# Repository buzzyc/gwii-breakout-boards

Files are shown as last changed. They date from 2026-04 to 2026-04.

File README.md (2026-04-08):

# G-Wii Breakout Boards

Custom KiCad breakout PCBs designed for the **G-Wii portable Wii** project. These boards replace the dozens of individual signal wires typically needed between the two halves of a portable Wii build with clean, modular PCBs and FFC (flat flex cable) connections.

Built in **KiCad 9.0**.

## Boards

### Daughterboard (`Daughterboard/`)
The central connector hub. Interfaces with the trimmed Wii motherboard and consolidates all control, audio, and video signals into organized connectors. Features a **GC+2.0** controller interface IC and a **UAMP** audio amplifier, routing button inputs (A/B/X/Y/Z, D-pad, triggers), analog stick axes, and stereo audio through a single interconnect system.

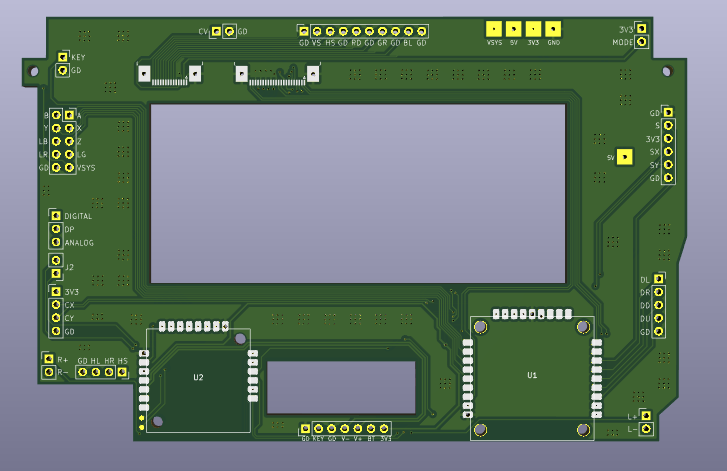
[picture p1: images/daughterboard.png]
Daughterboard PCB render


### Video FLX (`Video_FLX/`)
Video and signal breakout board that routes RGB video (RED, GREEN, BLUE), sync signals (H-Sync, V-Sync), audio lines, and control signals between the two halves of the portable via FFC cables — replacing what would otherwise be 20–30 individual wires.

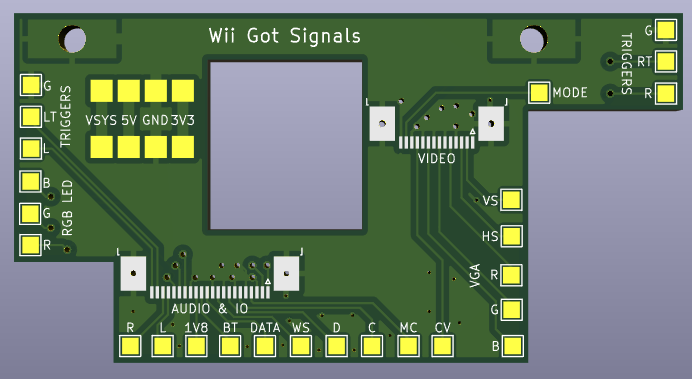
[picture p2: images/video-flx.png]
Video FLX PCB render


### ABXY (`ABXY/`)
Face button PCB for the A, B, X, Y, and Z buttons. Uses ALPS SKEYACA010 tactile switches and routes all button signals through a 6-pin connector back to the daughterboard. Also includes a mount for a common-anode tricolour (RGB) LED.

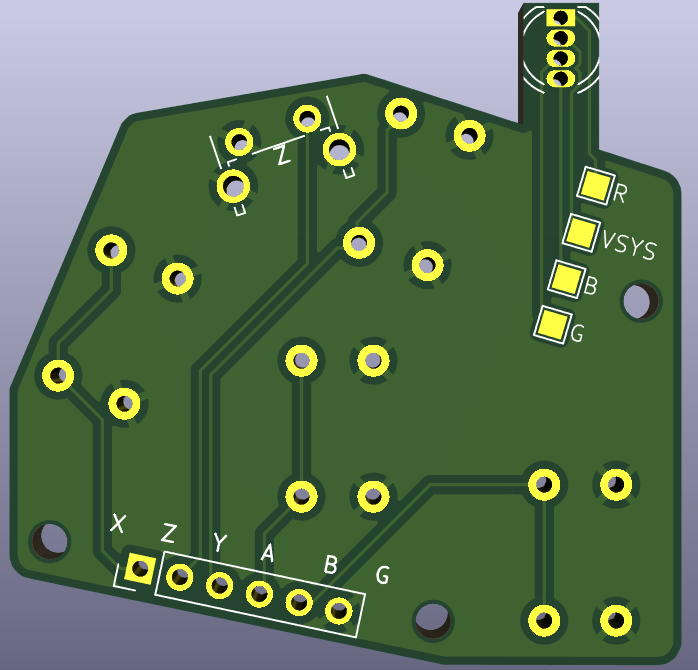
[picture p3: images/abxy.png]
ABXY PCB render


### D-Pad (`DPAD/`)
Directional pad button PCB for Up, Down, Left, and Right inputs.

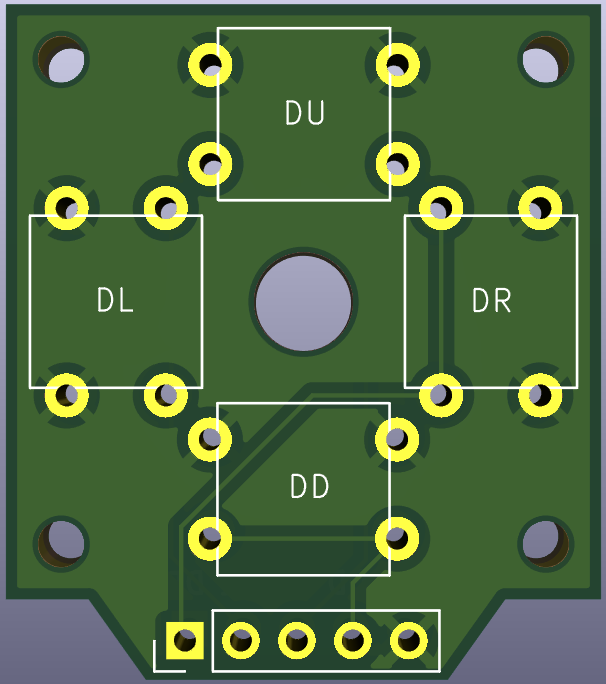
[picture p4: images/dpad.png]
D-Pad PCB render


### Joystick (`joystick/`)
Analog joystick breakout board. Provides connectors for joystick axis signals and mounting, routing back to the daughterboard.

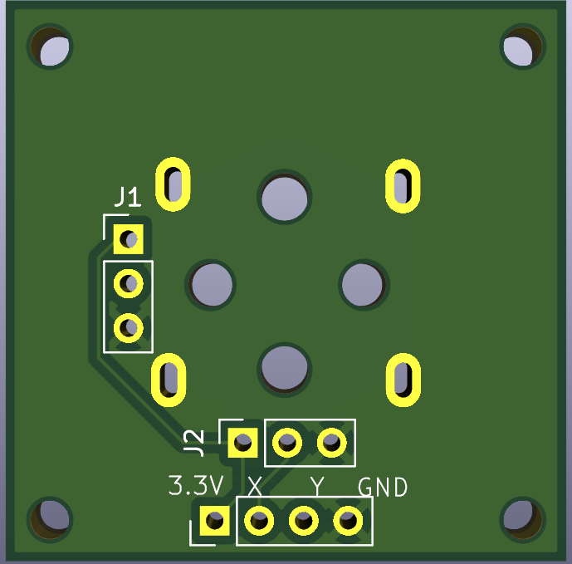
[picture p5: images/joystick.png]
Joystick PCB render


### Tactile Mount (`tactmount/`)
Tactile switch mounting board for auxiliary controls (Start, Select, Home, volume, etc.). Includes signal conditioning with pull-up resistors and decoupling capacitors.

The footprint labelled **SYNC** can act as either **SOURCE** or **Bluetooth sync** button depending on jumper configuration — position both jumpers at **1&2** for video source, or **2&3** for BT sync.

The resistor ladder on this board is designed around the **ZJ050NA-08C-KYV-N2** black VGA driver board (board reference](https://bitbuilt.net/forums/threads/resistor-value.6798/)).

Tactile Mount PCB front
Tactile Mount PCB rear

## Shared Libraries

- **`4LAYER_FOOTPRINTS.pretty`** — Custom footprints for 4LayerTech components (GC+2.0, PMS, UAMP, etc.)
- **`4LAYER_SCHEMATIC_SYMBOLS`** — Matching schematic symbols
- **`ALPS.pretty`** — ALPS SKEYACA010 tactile switch footprint (custom library — **note:** one of the GND pads is on the wrong side in the current footprint)

## Project Context

The [G-Wii](https://bitbuilt.net/forums/) is a portable Wii console build from the [BitBuilt](https://bitbuilt.net/) community. It uses a trimmed Wii motherboard fitted into a custom handheld case. These breakout boards make wiring significantly cleaner and more reliable by consolidating signals onto PCBs connected via FFC cables.

## License

Open hardware — use and modify freely for your own portable Wii builds.

> **Note:** These boards are not perfect and are provided as-is. You are more than welcome to modify them to suit your build.

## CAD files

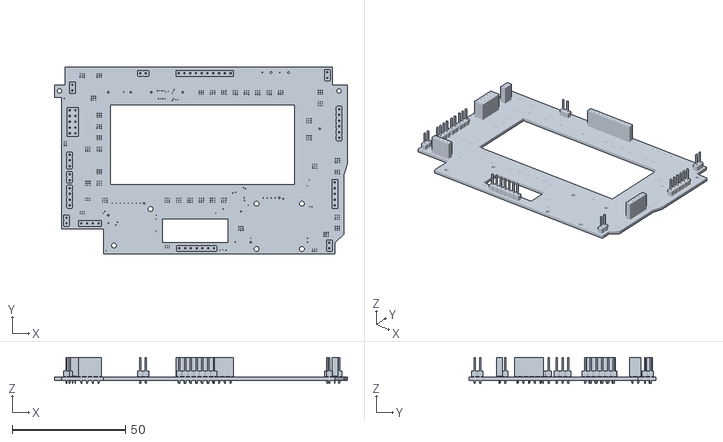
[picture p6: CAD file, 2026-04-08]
Daughterboard/daughterboard.stl
129.2 x 82.4 x 11.6

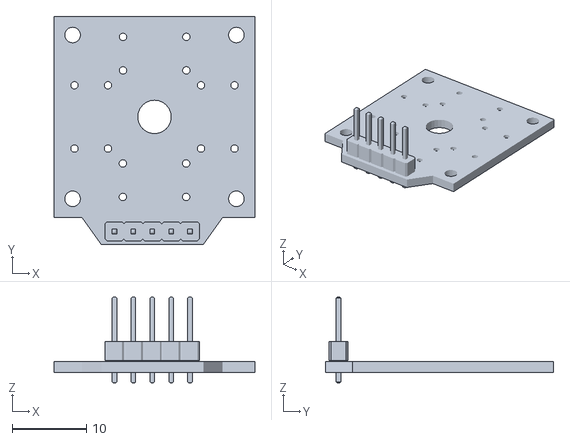
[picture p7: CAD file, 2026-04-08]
DPAD/DPAD.stl
27.0 x 30.7 x 11.5

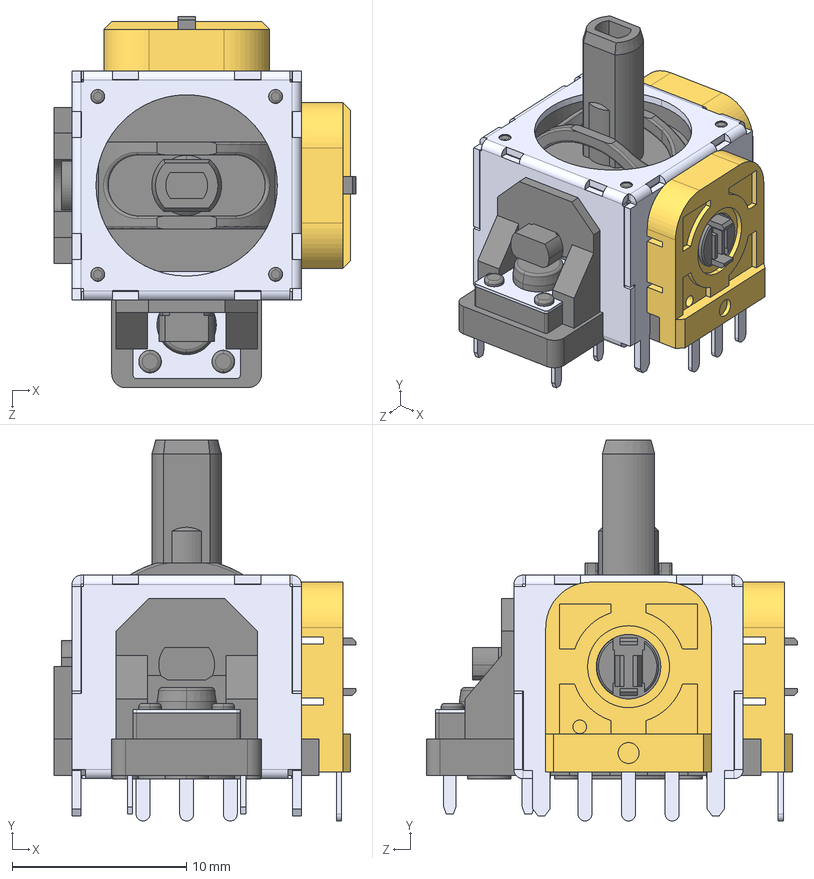
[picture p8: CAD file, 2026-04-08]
joystick/THB001P/THB001P.step
17.3 x 21.9 x 21.3 mm

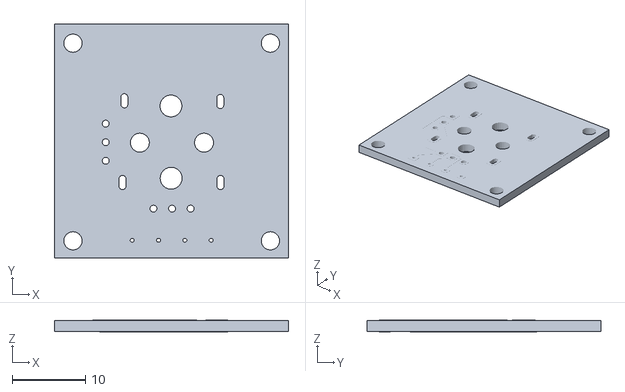
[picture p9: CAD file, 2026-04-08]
joystick/wii_breakout.stl
32.0 x 32.0 x 1.59

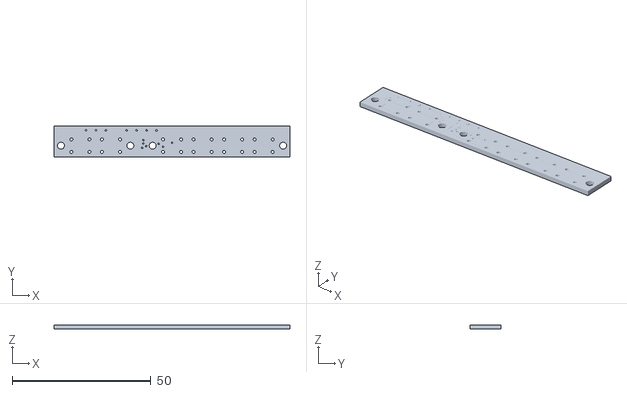
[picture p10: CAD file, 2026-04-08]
tactmount/tactmount.stl
85.0 x 11.0 x 1.58

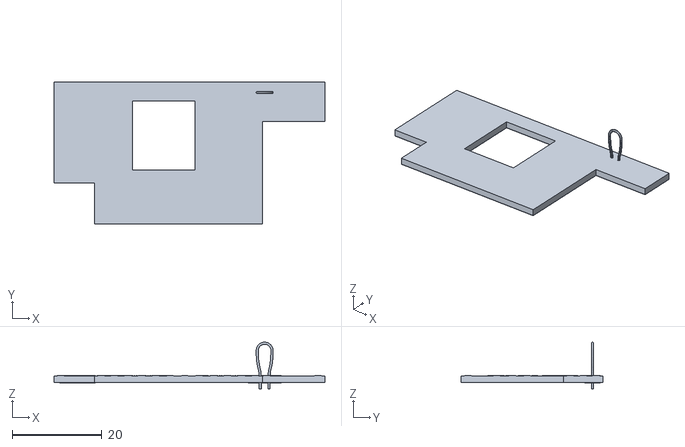
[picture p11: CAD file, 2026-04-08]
Video_FLX/video_flx.stl
60.5 x 31.6 x 10.4

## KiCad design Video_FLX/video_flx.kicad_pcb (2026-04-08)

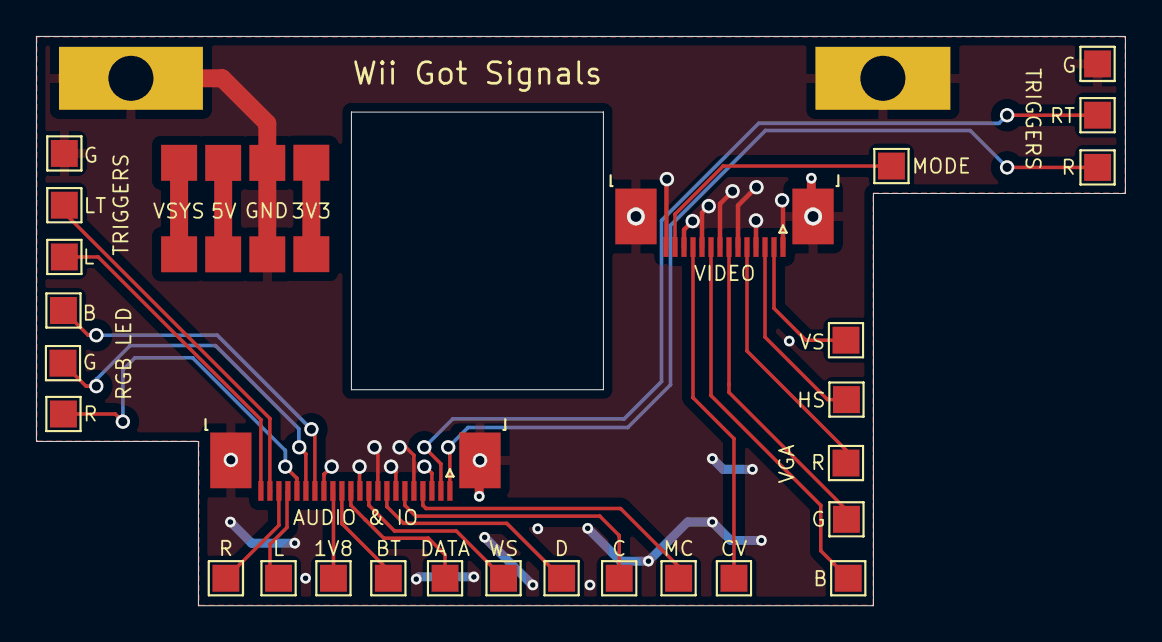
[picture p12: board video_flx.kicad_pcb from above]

Board: 2 copper layers, 60.5 x 31.6 mm, 27 parts (0 on the bottom side), 24 nets.

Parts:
1V8: TEST_1P; TestPoint_Pad_1.5x1.5mm
AUDIO & IO: Conn_01x16_MountingPin; TE_2-1734839-2_1x22-1MP_P0.5mm_Horizontal
B: TEST_1P; TestPoint_Pad_1.5x1.5mm
B#2: TEST_1P; TestPoint_Pad_1.5x1.5mm
BT: TEST_1P; TestPoint_Pad_1.5x1.5mm
C: TEST_1P; TestPoint_Pad_1.5x1.5mm
CV: TEST_1P; TestPoint_Pad_1.5x1.5mm
D: TEST_1P; TestPoint_Pad_1.5x1.5mm
DATA: TEST_1P; TestPoint_Pad_1.5x1.5mm
G: TEST_1P; TestPoint_Pad_1.5x1.5mm
G#2, G#3, G#4: TEST_1P; TestPoint_Pad_1.5x1.5mm
HS: TEST_1P; TestPoint_Pad_1.5x1.5mm
L: TEST_1P; TestPoint_Pad_1.5x1.5mm
L#2: TEST_1P; TestPoint_Pad_1.5x1.5mm
LT: TEST_1P; TestPoint_Pad_1.5x1.5mm
MC: TEST_1P; TestPoint_Pad_1.5x1.5mm
MODE: TEST_1P; TestPoint_Pad_1.5x1.5mm
R: TEST_1P; TestPoint_Pad_1.5x1.5mm
R#2, R#3, R#4: TEST_1P; TestPoint_Pad_1.5x1.5mm
RT: TEST_1P; TestPoint_Pad_1.5x1.5mm
VIDEO: Conn_01x14_MountingPin; TE_1-1734839-4_1x14-1MP_P0.5mm_Horizontal
VS: TEST_1P; TestPoint_Pad_1.5x1.5mm
WS: TEST_1P; TestPoint_Pad_1.5x1.5mm

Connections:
+1V8: 1V8.1, AUDIO & IO.14
BLUE: B.1, VIDEO.9
BT: AUDIO & IO.13, BT.1
C: AUDIO & IO.6, C.1
CDATA: AUDIO & IO.12, DATA.1
CV: CV.1, VIDEO.11
D: AUDIO & IO.8, D.1
GND: AUDIO & IO.3, AUDIO & IO.5, AUDIO & IO.7, AUDIO & IO.9, AUDIO & IO.11, AUDIO & IO.15, AUDIO & IO.MP (MountPin), G#2.1, G#4.1, VIDEO.1, VIDEO.4, VIDEO.6, VIDEO.8, VIDEO.10, VIDEO.12, VIDEO.14, VIDEO.MP (MountPin)
GREEN: G#3.1, VIDEO.7
HS: HS.1, VIDEO.3
L: AUDIO & IO.19, L.1
LA: AUDIO & IO.22, L#2.1
LEDB: AUDIO & IO.16, B#2.1
LEDG: AUDIO & IO.17, G.1
LEDR: AUDIO & IO.18, R#2.1
LT: AUDIO & IO.21, LT.1
MC: AUDIO & IO.4, MC.1
MODE: MODE.1, VIDEO.13
R: AUDIO & IO.20, R#3.1
RA: AUDIO & IO.1, R.1
RED: R#4.1, VIDEO.5
RT: AUDIO & IO.2, RT.1
VS: VIDEO.2, VS.1
WS: AUDIO & IO.10, WS.1

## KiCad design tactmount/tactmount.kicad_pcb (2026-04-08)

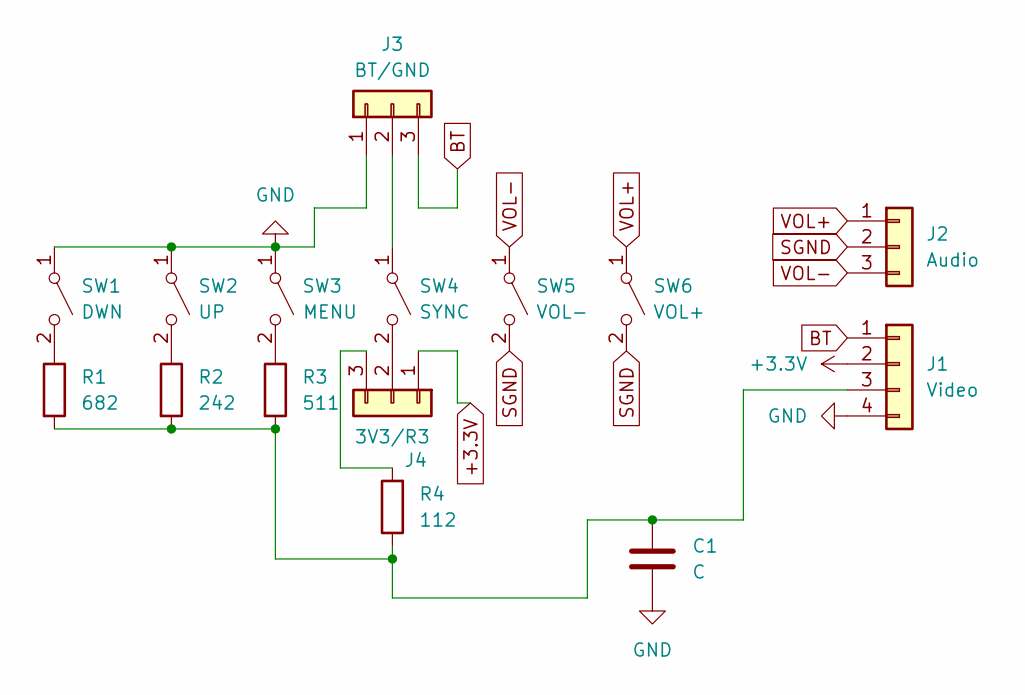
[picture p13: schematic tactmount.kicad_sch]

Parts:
C1: C; C_0603_1608Metric_Pad1.08x0.95mm_HandSolder
J1: Video; SolderWire-0.1sqmm_1x04_P3.6mm_D0.4mm_OD1mm
J2: Audio; SolderWire-0.1sqmm_1x03_P3.6mm_D0.4mm_OD1mm
J3: BT/GND; PinHeader_1x03_P2.54mm_Vertical
J4: 3V3/R3; PinHeader_1x03_P2.54mm_Vertical
R1: 682; R_0603_1608Metric_Pad0.98x0.95mm_HandSolder
R2: 242; R_0603_1608Metric_Pad0.98x0.95mm_HandSolder
R3: 511; R_0603_1608Metric_Pad0.98x0.95mm_HandSolder
R4: 112; R_0603_1608Metric_Pad0.98x0.95mm_HandSolder
SW1: DWN; SW_PUSH_6mm_H7.3mm
SW2: UP; SW_PUSH_6mm_H7.3mm
SW3: MENU; SW_PUSH_6mm_H7.3mm
SW4: SYNC; SW_PUSH_6mm_H7.3mm
SW5: VOL-; SW_PUSH_6mm_H7.3mm
SW6: VOL+; SW_PUSH_6mm_H7.3mm

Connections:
+3.3V: J1.2, J4.1
BT: J1.1, J3.3
GND: C1.2, J1.4, J3.1, SW1.1 (A), SW2.1 (A), SW3.1 (A)
unnamed: C1.1, J1.3, R1.2, R2.2, R3.2, R4.1
unnamed: J3.2, SW4.1 (A)
unnamed: J4.2, SW4.2 (B)
unnamed: J4.3, R4.2
unnamed: R1.1, SW1.2 (B)
unnamed: R2.1, SW2.2 (B)
unnamed: R3.1, SW3.2 (B)
SGND: J2.2, SW5.2 (B), SW6.2 (B)
VOL+: J2.1, SW6.1 (A)
VOL-: J2.3, SW5.1 (A)

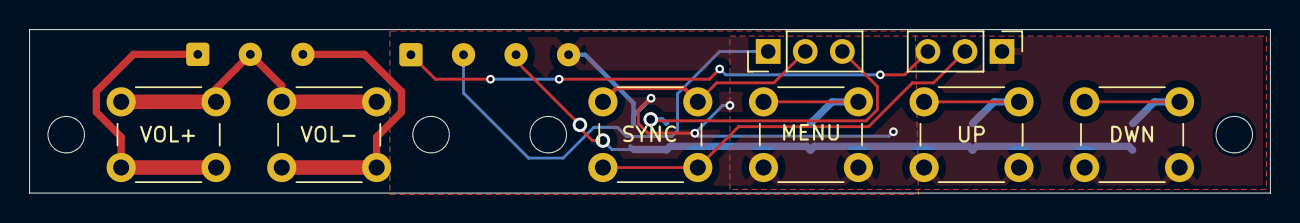
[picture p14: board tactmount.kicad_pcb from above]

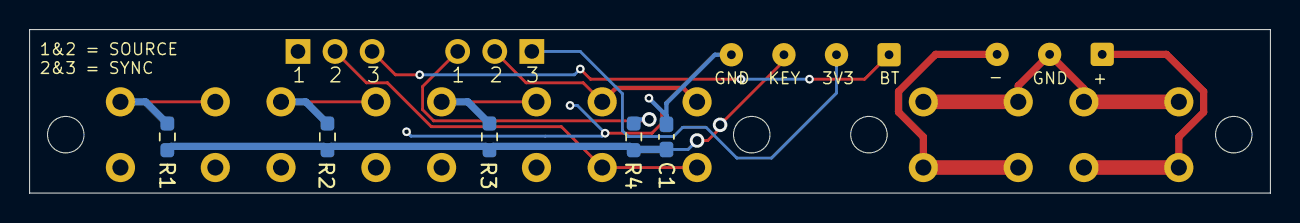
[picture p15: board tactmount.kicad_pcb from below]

Board: 2 copper layers, 85.0 x 11.2 mm, 15 parts (5 on the bottom side), 13 nets.

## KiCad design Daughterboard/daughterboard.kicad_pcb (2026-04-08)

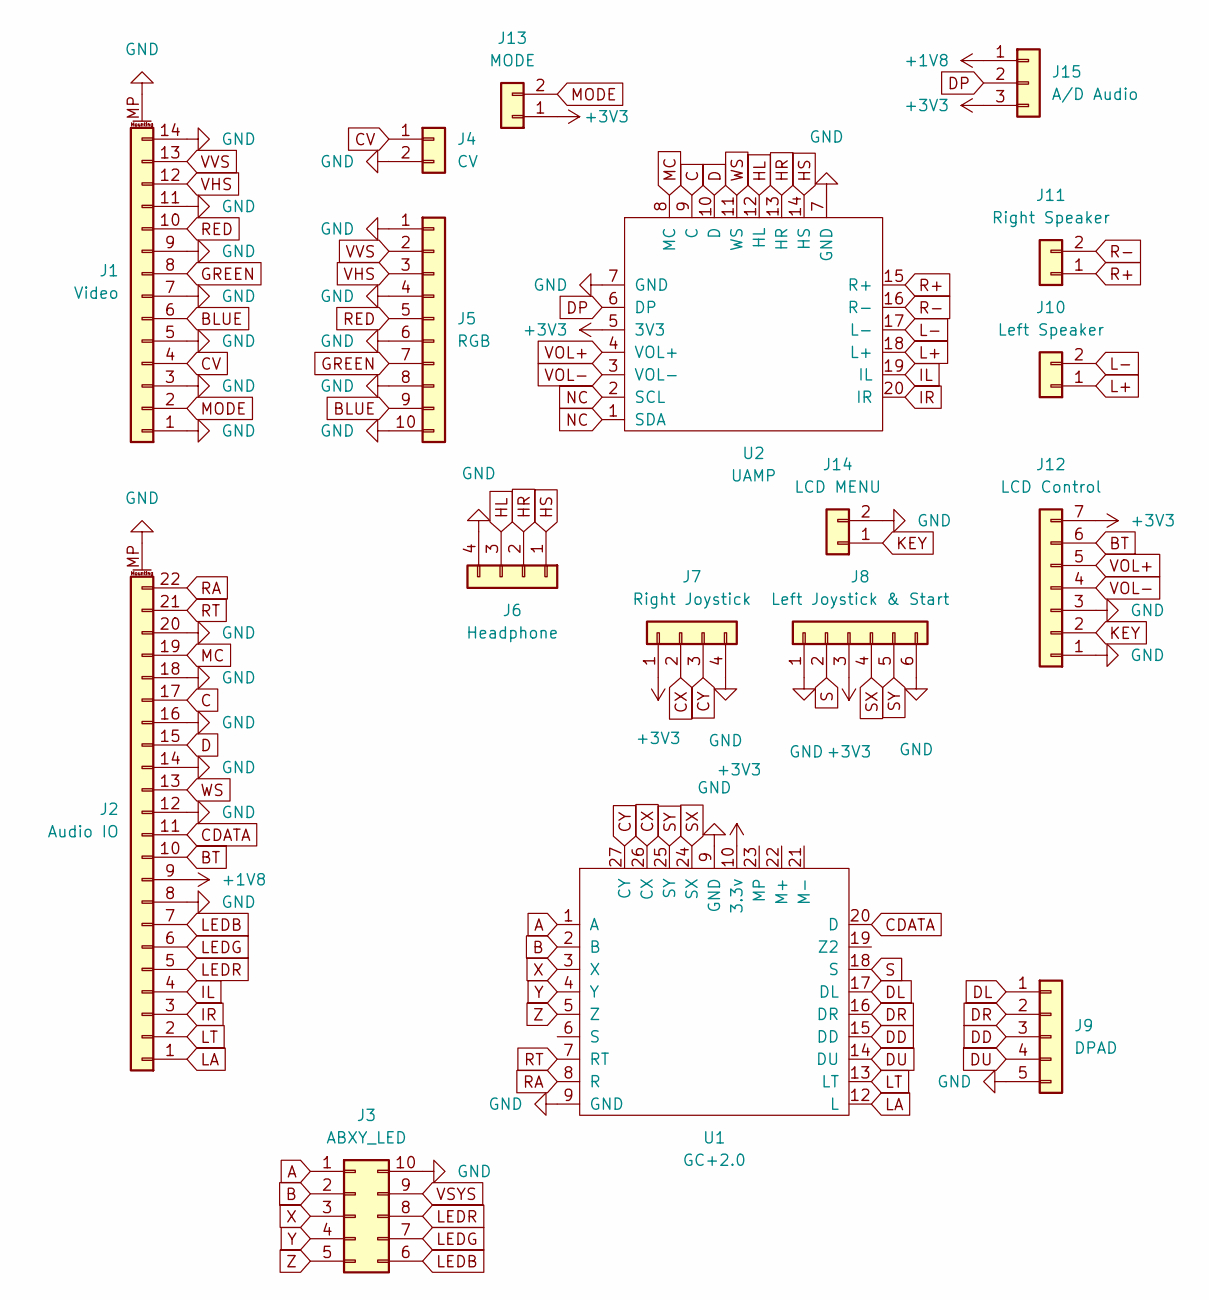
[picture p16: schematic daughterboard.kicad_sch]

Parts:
J1: Video; TE_1-1734839-4_1x14-1MP_P0.5mm_Horizontal
J2: Audio IO; TE_2-1734839-2_1x22-1MP_P0.5mm_Horizontal
J3: ABXY_LED; PinSocket_2x05_P2.54mm_Vertical
J4: CV; PinHeader_1x02_P2.54mm_Vertical
J5: RGB; PinSocket_1x10_P2.54mm_Vertical
J6: Headphone; PinSocket_1x04_P2.54mm_Vertical
J7: Right Joystick; PinHeader_1x04_P2.54mm_Vertical
J8: Left Joystick & Start; PinHeader_1x06_P2.54mm_Vertical
J9: DPAD; PinSocket_1x05_P2.54mm_Vertical
J10: Left Speaker; PinHeader_1x02_P2.54mm_Vertical
J11: Right Speaker; PinHeader_1x02_P2.54mm_Vertical
J12: LCD Control; PinHeader_1x07_P2.54mm_Vertical
J13: MODE; PinHeader_1x02_P2.54mm_Vertical
J14: LCD MENU; PinSocket_1x02_P2.54mm_Vertical
J15: A/D Audio; PinHeader_1x03_P2.54mm_Vertical
U1: GC+2.0
U2: UAMP; UAMP2

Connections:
+1V8: J2.9, J15.1
+3V3: J7.1, J8.3, J12.7, J13.1, J15.3, U1.10 (3.3v), U2.5 (3V3)
A: J3.1, U1.1 (A)
B: J3.2, U1.2 (B)
BLUE: J1.6, J5.9
BT: J2.10, J12.6
C: J2.17, U2.9 (C)
CDATA: J2.11, U1.20 (D)
CV: J1.4, J4.1
CX: J7.2, U1.26 (CX)
CY: J7.3, U1.27 (CY)
D: J2.15, U2.10 (D)
DD: J9.3, U1.15 (DD)
DL: J9.1, U1.17 (DL)
DP: J15.2, U2.6 (DP)
DR: J9.2, U1.16 (DR)
DU: J9.4, U1.14 (DU)
GND: J1.1, J1.3, J1.5, J1.7, J1.9, J1.11, J1.14, J1.MP (MountPin), J2.8, J2.12, J2.14, J2.16, J2.18, J2.20, J2.MP (MountPin), J3.10, J4.2, J5.1, J5.4, J5.6, J5.8, J5.10, J6.4, J7.4, J8.1, J8.6, J9.5, J12.1, J12.3, J14.2, U1.9 (GND), U2.7 (GND)
GREEN: J1.8, J5.7
HL: J6.3, U2.12 (HL)
HR: J6.2, U2.13 (HR)
HS: J6.1, U2.14 (HS)
IL: J2.4, U2.19 (IL)
IR: J2.3, U2.20 (IR)
KEY: J12.2, J14.1
L+: J10.1, U2.18 (L+)
L-: J10.2, U2.17 (L-)
LA: J2.1, U1.12 (L)
LEDB: J2.7, J3.6
LEDG: J2.6, J3.7
LEDR: J2.5, J3.8
LT: J2.2, U1.13 (LT)
MC: J2.19, U2.8 (MC)
MODE: J1.2, J13.2
R+: J11.1, U2.15 (R+)
R-: J11.2, U2.16 (R-)
RA: J2.22, U1.8 (R)
RED: J1.10, J5.5
RT: J2.21, U1.7 (RT)
S: J8.2, U1.18 (S)
SX: J8.4, U1.24 (SX)
SY: J8.5, U1.25 (SY)
VHS: J1.12, J5.3
VOL+: J12.5, U2.4 (VOL+)
VOL-: J12.4, U2.3 (VOL-)
VSYS: J3.9
VVS: J1.13, J5.2
WS: J2.13, U2.11 (WS)
X: J3.3, U1.3 (X)
Y: J3.4, U1.4 (Y)
Z: J3.5, U1.5 (Z)

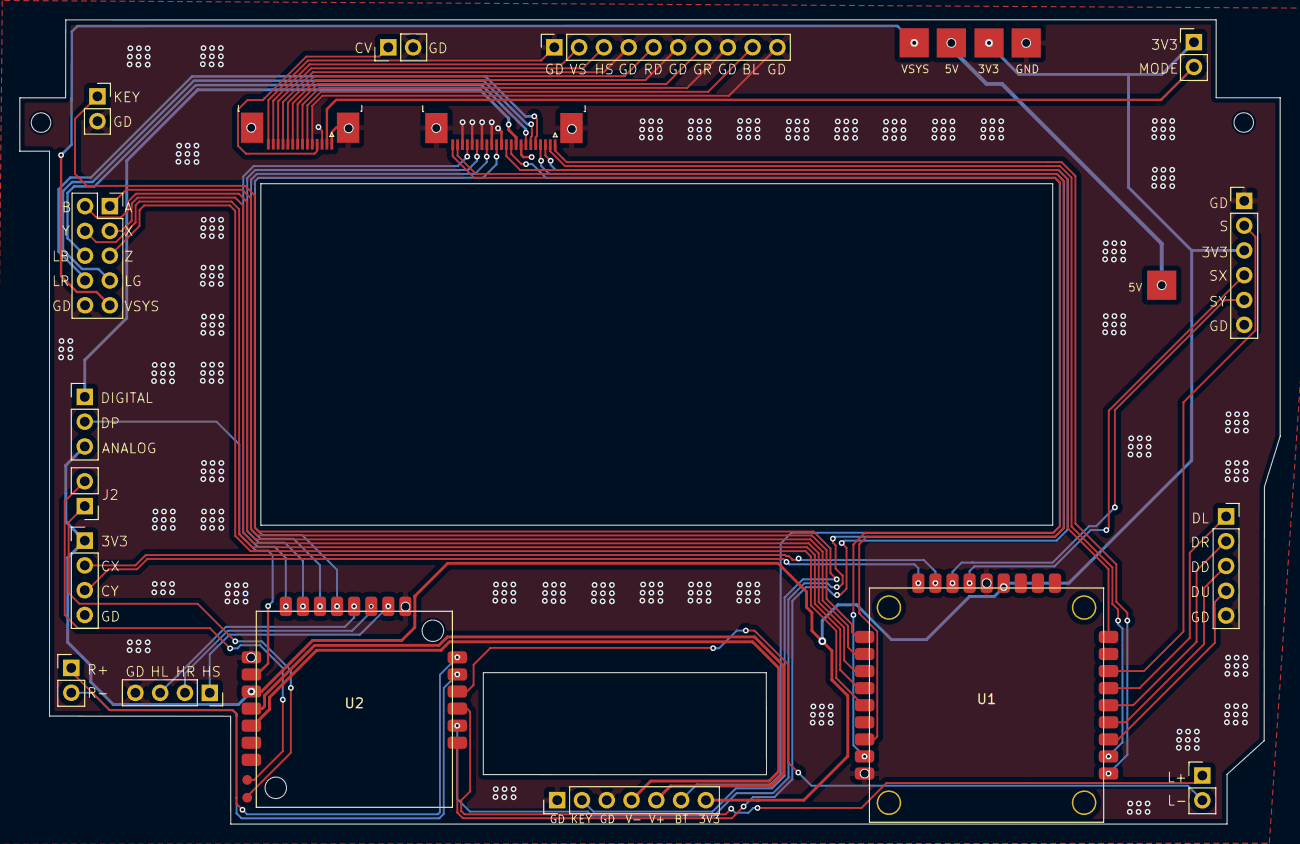
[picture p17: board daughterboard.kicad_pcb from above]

Board: 2 copper layers, 129.2 x 82.4 mm, 18 parts (0 on the bottom side), 50 nets.

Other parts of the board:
J11#2: Right Speaker; PinHeader_1x02_P2.54mm_Vertical

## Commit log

2026-04-08 Initial commit: G-Wii breakout board KiCad projects
    Custom breakout PCBs for the G-Wii portable Wii build.
    Replaces 20-30 individual signal wires with modular PCBs and FFC cables.
    Boards included:
    - Daughterboard: Central connector hub with GC+2.0 and UAMP
    - Video FLX: Video/audio signal routing via FFC cables
    - ABXY: Face button PCB (A/B/X/Y/Z)
    - DPAD: Directional pad PCB
    - Joystick: Analog joystick breakout
    - Tactile Mount: Auxiliary control buttons
    [BCY-B_Cu.gbl, BCY-B_Mask.gbs, BCY-B_Paste.gbp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]
2026-04-08 Add PCB render images and update README
    - Add daughterboard and Video FLX board renders
    - Note ABXY board includes tricolour LED mount (common anode)
    - Note ALPS footprint GND pad issue
2026-04-08 Add remaining board images and update README
    - Add renders for ABXY, DPAD, joystick, and tactmount (front/rear)
    - Document tactmount SYNC/BT sync jumper configuration
    - Note resistor ladder designed for ZJ050NA-08C VGA driver board
    - Add open modification disclaimer
2026-04-08 Update tactmount resistor ladder reference to correct thread
2026-04-08 Clarify SYNC footprint functionality in README
    Updated the description of the SYNC footprint to clarify its dual functionality.
